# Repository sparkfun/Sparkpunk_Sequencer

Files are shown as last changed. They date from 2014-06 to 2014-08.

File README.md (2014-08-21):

SparkPunk Sequencer
===================

[SparkPunk Sequencer
*SparkPunk Sequencer(KIT-12707)*](https://www.sparkfun.com/products/12707)

The SparkPunk Sequencer is a musical control voltage sequencer designed to control the 
[SparkPunk Sound Generator](https://www.sparkfun.com/products/11177). 
With the pair, you can create ten-step musical motifs, but there are hidden opportunities in the sequencer: 
it can be modified and connected to external hardware in clever and interesting ways. 

Board comes as a soldering kit. 

Repository Contents
-------------------
* **/Hardware** - All Eagle design files (.brd, .sch, .STL)
* **/Sims** - LTSpice files

License Information
-------------------
The hardware is released under [Creative Commons ShareAlike 4.0 International](https://creativecommons.org/licenses/by-sa/4.0/).

Distributed as-is; no warranty is given.

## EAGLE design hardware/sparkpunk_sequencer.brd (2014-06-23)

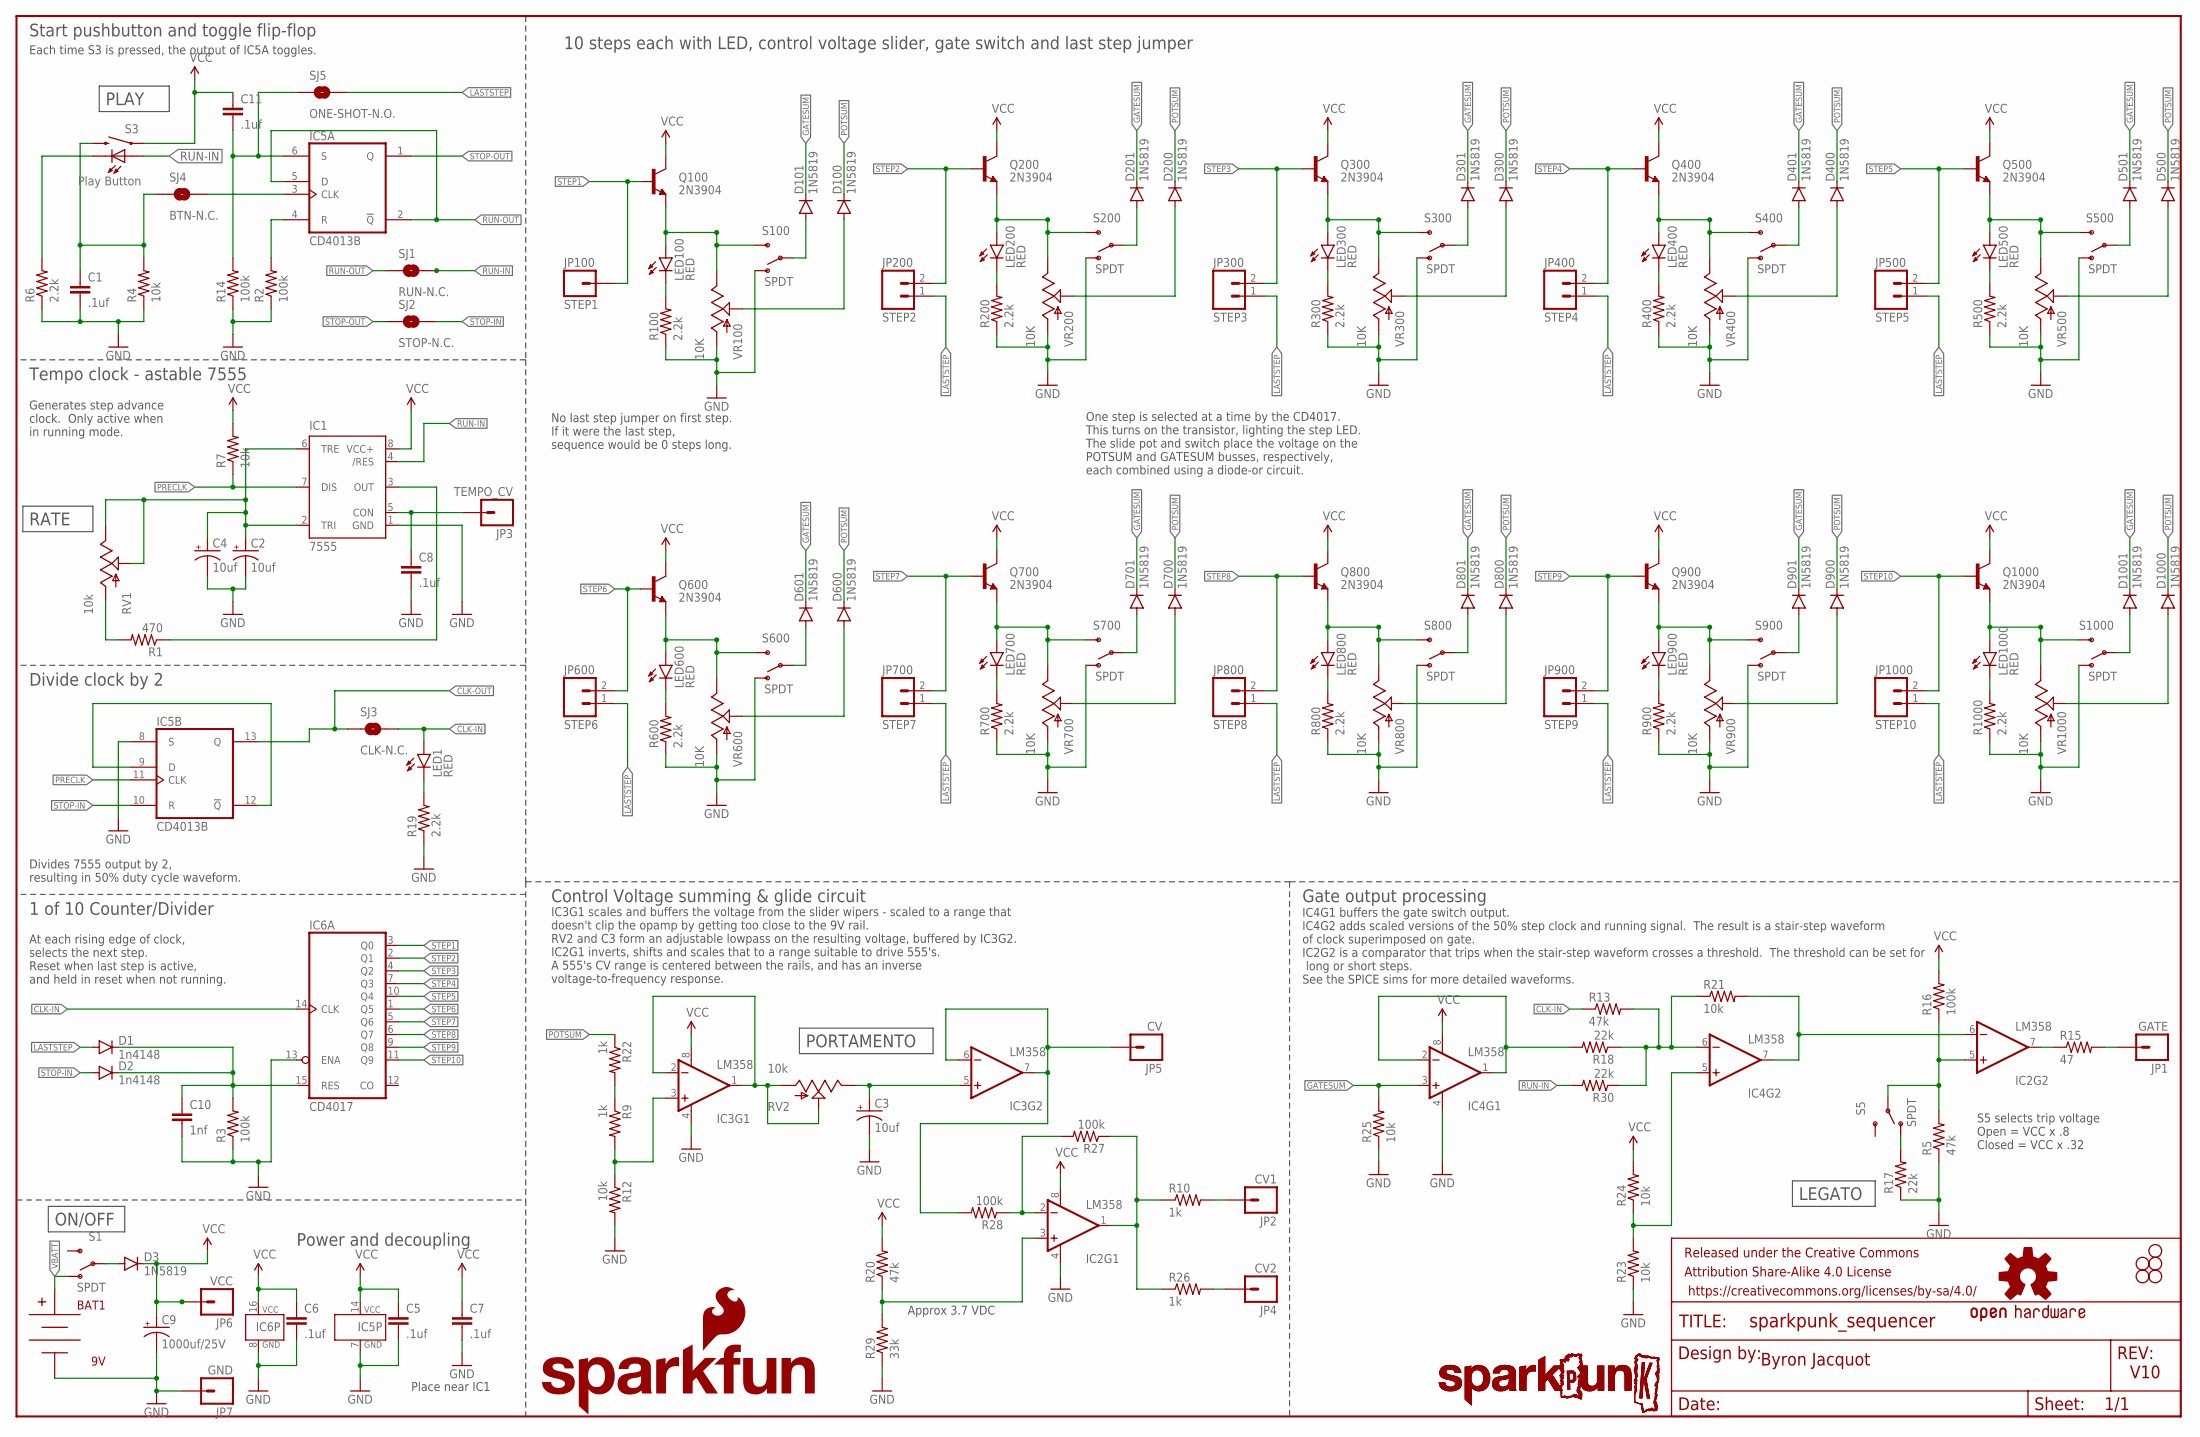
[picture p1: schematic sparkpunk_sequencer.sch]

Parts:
BAT1: 9V; BC9VPC_KIT
C1, C5, C6, C7, C8, C11: .1uf; CAP-PTH-SMALL-KIT
C2, C3, C4: 10uf; CPOL-RADIAL-10UF-25V-KIT
C9: 1000uf/25V; CPOL-RADIAL-1000UF-25V-KIT
C10: 1nf; CAP-PTH-SMALL-KIT
D1, D2: 1n4148; DIODE-1N4148-KIT
D3, D100, D101, D200, D201, D300, D301, D400, D401, D500, D501, D600, D601, D700, D701, D800, D801, D900, D901, D1000, D1001: 1N5819; DIODE-1N4001-KIT
FRAME1: FRAME-LEDGER; CREATIVE_COMMONS
IC1: 7555; DIP08-KIT
IC2, IC3, IC4: LM358; DIP08-KIT
IC5: CD4013B; DIL14-KIT
IC6: CD4017; DIL16-KIT
JP1: GATE; 1X01NS
JP2: CV1; 1X01NS
JP3: TEMPO_CV; 1X01NS
JP4: CV2; 1X01NS
JP5: CV; 1X01NS
JP6: VCC; 1X01NS
JP7: GND; 1X01NS
JP100: STEP1; 1X01NS
JP200: STEP2; 1X02_NO_SILK
JP300: STEP3; 1X02_NO_SILK
JP400: STEP4; 1X02_NO_SILK
JP500: STEP5; 1X02_NO_SILK
JP600: STEP6; 1X02_NO_SILK
JP700: STEP7; 1X02_NO_SILK
JP800: STEP8; 1X02_NO_SILK
JP900: STEP9; 1X02_NO_SILK
JP1000: STEP10; 1X02_NO_SILK
LED1, LED100, LED200, LED300, LED400, LED500, LED600, LED700, LED800, LED900, LED1000: RED; LED5MM-KIT
LOGO1: SPARKPUNK_LOGO.2_INCH_TALL; SPARKPUNK_LOGO_.2
LOGO2: OSHW-LOGOM; OSHW-LOGO-M
LOGO3: SPARKPUNK_LOGO.1INCH_TALL; SPARKPUNK_LOGO_.1
LOGO4: SFE_LOGO_NAME_FLAME.4_INCH; SFE_LOGO_NAME_FLAME_.4
Q100, Q200, Q300, Q400, Q500, Q600, Q700, Q800, Q900, Q1000: 2N3904; TO-92-AMMO
R1: 470; AXIAL-0.3EZ
R2, R3, R14, R16, R27, R28: 100k; AXIAL-0.3EZ
R4, R7, R12, R21, R23, R24, R25: 10k; AXIAL-0.3EZ
R5, R13, R20: 47k; AXIAL-0.3EZ
R6, R19, R100, R200, R300, R400, R500, R600, R700, R800, R900, R1000: 2.2k; AXIAL-0.3EZ
R9, R10, R22, R26: 1k; AXIAL-0.3EZ
R15: 47; AXIAL-0.3EZ
R17, R18, R30: 22k; AXIAL-0.3EZ
R29: 33k; AXIAL-0.3EZ
RV1, RV2: 10k; ALPS_POT_KIT
S1, S5, S100, S200, S300, S400, S500, S600, S700, S800, S900, S1000: SPDT; SWITCH-SPDT_KIT
S3: Play Button; TACTILE-PTH-LED-12MM-EZ
SJ1: RUN-N.C.; SJ_2S-TRACE-PTH
SJ2: STOP-N.C.; SJ_2S-TRACE-PTH
SJ3: CLK-N.C.; SJ_2S-TRACE-PTH
SJ4: BTN-N.C.; SJ_2S-TRACE-PTH
SJ5: ONE-SHOT-N.O.; SJ_2S-PTH
STANDOFF1, STANDOFF2, STANDOFF3, STANDOFF5, STANDOFF6: STAND-OFF
VR100, VR200, VR300, VR400, VR500, VR600, VR700, VR800, VR900, VR1000: 10K; SLIDER-MEDIUM-KIT

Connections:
555OUT: IC1.3 (OUT), R1.P$1 (1)
BTN-OUT: C1.1, R4.P$2 (2), S3.2, SJ4.1
CLK-IN: IC6.14 (CLK), LED1.A, R13.P$1 (1), SJ3.2
CLK-OUT: IC5.13 (Q), SJ3.1
GATESUM: D101.C, D201.C, D301.C, D401.C, D501.C, D601.C, D701.C, D801.C, D901.C, D1001.C, IC4.3 (+IN), R25.P$2 (2)
GND: BAT1.V-, C1.2, C2.2 (-), C3.2 (-), C4.2 (-), C5.2, C6.2, C7.2, C8.2, C9.-, C10.2, IC1.1 (GND), IC2.4 (V-), IC3.4 (V-), IC4.4 (V-), IC5.7 (GND), IC5.8 (S), IC6.8 (GND), IC6.13 (ENA), JP7.1, R2.P$1 (1), R3.P$1 (1), R4.P$1 (1), R5.P$1 (1), R6.P$1 (1), R12.P$2 (2), R14.P$1 (1), R17.P$1 (1), R19.P$1 (1), R23.P$1 (1), R25.P$1 (1), R29.P$1 (1), R100.P$1 (1), R200.P$1 (1), R300.P$1 (1), R400.P$1 (1), R500.P$1 (1), R600.P$1 (1), R700.P$1 (1), R800.P$1 (1), R900.P$1 (1), R1000.P$1 (1), S100.1 (O), S200.1 (O), S300.1 (O), S400.1 (O), S500.1 (O), S600.1 (O), S700.1 (O), S800.1 (O), S900.1 (O), S1000.1 (O), VR100.BOTTOM (A), VR200.BOTTOM (A), VR300.BOTTOM (A), VR400.BOTTOM (A), VR500.BOTTOM (A), VR600.BOTTOM (A), VR700.BOTTOM (A), VR800.BOTTOM (A), VR900.BOTTOM (A), VR1000.BOTTOM (A)
LASTSTEP: D1.A, JP200.1, JP300.1, JP400.1, JP500.1, JP600.1, JP700.1, JP800.1, JP900.1, JP1000.1, SJ5.2
unnamed: LED100.A, Q100.1 (E), S100.3 (S), VR100.TOP (E)
unnamed: LED100.K (C), R100.P$2 (2)
unnamed: D101.A, S100.2
unnamed: D100.A, VR100.WIPER (S)
unnamed: R1.P$2 (2), RV1.P$3 (A)
unnamed: IC3.1 (OUT), IC3.2 (-IN), RV2.P$2 (S), RV2.P$3 (A)
unnamed: C8.1, IC1.5 (CON), JP3.1
unnamed: R6.P$2 (2), S3.C
unnamed: IC5.4 (R), R2.P$2 (2)
unnamed: C2.1 (+), C4.1 (+), IC1.2 (TRI), IC1.6 (TRE), RV1.P$1 (E), RV1.P$2 (S)
unnamed: IC4.1 (OUT), IC4.2 (-IN), R18.P$2 (2)
unnamed: LED1.K (C), R19.P$2 (2)
unnamed: C10.1, D1.C, D2.C, IC6.15 (RES), R3.P$2 (2)
unnamed: IC3.3 (+IN), R9.P$2 (2), R12.P$1 (1)
unnamed: R9.P$1 (1), R22.P$2 (2)
unnamed: IC2.2 (-IN), R27.P$2 (2), R28.P$1 (1)
unnamed: C3.1 (+), IC3.5 (+IN), RV2.P$1 (E)
unnamed: IC2.3 (+IN), R20.P$1 (1), R29.P$2 (2)
unnamed: JP1.1, R15.P$2 (2)
unnamed: IC5.3 (CLK), SJ4.2
unnamed: IC2.5 (+IN), R5.P$2 (2), R16.P$1 (1), S5.2
unnamed: IC2.7 (OUT), R15.P$1 (1)
unnamed: R17.P$2 (2), S5.1 (O)
unnamed: IC5.9 (D), IC5.12 (!Q)
unnamed: LED200.A, Q200.1 (E), S200.3 (S), VR200.TOP (E)
unnamed: LED200.K (C), R200.P$2 (2)
unnamed: D200.A, VR200.WIPER (S)
unnamed: D201.A, S200.2
unnamed: LED300.A, Q300.1 (E), S300.3 (S), VR300.TOP (E)
unnamed: LED300.K (C), R300.P$2 (2)
unnamed: D300.A, VR300.WIPER (S)
unnamed: D301.A, S300.2
unnamed: LED400.A, Q400.1 (E), S400.3 (S), VR400.TOP (E)
unnamed: LED400.K (C), R400.P$2 (2)
unnamed: D400.A, VR400.WIPER (S)
unnamed: D401.A, S400.2
unnamed: LED500.A, Q500.1 (E), S500.3 (S), VR500.TOP (E)
unnamed: LED500.K (C), R500.P$2 (2)
unnamed: D500.A, VR500.WIPER (S)
unnamed: D501.A, S500.2
unnamed: LED600.A, Q600.1 (E), S600.3 (S), VR600.TOP (E)
unnamed: LED600.K (C), R600.P$2 (2)
unnamed: D600.A, VR600.WIPER (S)
unnamed: D601.A, S600.2
unnamed: LED700.A, Q700.1 (E), S700.3 (S), VR700.TOP (E)
unnamed: LED700.K (C), R700.P$2 (2)
unnamed: D700.A, VR700.WIPER (S)
unnamed: D701.A, S700.2
unnamed: LED800.A, Q800.1 (E), S800.3 (S), VR800.TOP (E)
unnamed: LED800.K (C), R800.P$2 (2)
unnamed: D800.A, VR800.WIPER (S)
unnamed: D801.A, S800.2
unnamed: LED900.A, Q900.1 (E), S900.3 (S), VR900.TOP (E)
unnamed: LED900.K (C), R900.P$2 (2)
unnamed: D900.A, VR900.WIPER (S)
unnamed: D901.A, S900.2
unnamed: LED1000.A, Q1000.1 (E), S1000.3 (S), VR1000.TOP (E)
unnamed: LED1000.K (C), R1000.P$2 (2)
unnamed: D1000.A, VR1000.WIPER (S)
unnamed: D1001.A, S1000.2
unnamed: C11.2, IC5.6 (S), R14.P$2 (2), SJ5.1
unnamed: IC4.6 (-IN), R13.P$2 (2), R18.P$1 (1), R21.P$1 (1), R30.P$1 (1)
unnamed: IC3.6 (-IN), IC3.7 (OUT), JP5.1, R28.P$2 (2)
unnamed: IC2.1 (OUT), R10.P$1 (1), R26.P$1 (1), R27.P$1 (1)
unnamed: JP4.1, R26.P$2 (2)
unnamed: JP2.1, R10.P$2 (2)
unnamed: IC2.6 (-IN), IC4.7 (OUT), R21.P$2 (2)
unnamed: IC4.5 (+IN), R23.P$2 (2), R24.P$1 (1)
unnamed: D3.A, S1.2
POTSUM: D100.C, D200.C, D300.C, D400.C, D500.C, D600.C, D700.C, D800.C, D900.C, D1000.C, R22.P$1 (1)
PRECLK: IC1.7 (DIS), IC5.11 (CLK), R7.P$1 (1)
RUN-IN: IC1.4 (/RES), R30.P$2 (2), S3.A, SJ1.2
RUN-OUT: IC5.2 (!Q), IC5.5 (D), SJ1.1
STEP1: IC6.3 (Q0), JP100.1, Q100.2 (B)
STEP2: IC6.2 (Q1), JP200.2, Q200.2 (B)
STEP3: IC6.4 (Q2), JP300.2, Q300.2 (B)
STEP4: IC6.7 (Q3), JP400.2, Q400.2 (B)
STEP5: IC6.10 (Q4), JP500.2, Q500.2 (B)
STEP6: IC6.1 (Q5), JP600.2, Q600.2 (B)
STEP7: IC6.5 (Q6), JP700.2, Q700.2 (B)
STEP8: IC6.6 (Q7), JP800.2, Q800.2 (B)
STEP9: IC6.9 (Q8), JP900.2, Q900.2 (B)
STEP10: IC6.11 (Q9), JP1000.2, Q1000.2 (B)
STOP-IN: D2.A, IC5.10 (R), SJ2.2
STOP-OUT: IC5.1 (Q), SJ2.1
VBATT: BAT1.V+, S1.1 (O)
VCC: C5.1, C6.1, C7.1, C9.+, C11.1, D3.C, IC1.8 (VCC+), IC2.8 (V+), IC3.8 (V+), IC4.8 (V+), IC5.14 (VCC), IC6.16 (VCC), JP6.1, Q100.3 (C), Q200.3 (C), Q300.3 (C), Q400.3 (C), Q500.3 (C), Q600.3 (C), Q700.3 (C), Q800.3 (C), Q900.3 (C), Q1000.3 (C), R7.P$2 (2), R16.P$2 (2), R20.P$2 (2), R24.P$2 (2), S3.4 (1)

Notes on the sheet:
Byron Jacquot
V10
LEGATO
PORTAMENTO
RATE
PLAY
Place near IC1
Power and decoupling
1 of 10 Counter/Divider
Divide clock by 2
Tempo clock - astable 7555
Start pushbutton and toggle flip-flop
Control Voltage summing & glide circuit
Gate output processing
10 steps each with LED, control voltage slider, gate switch and last step jumper
No last step jumper on first step. If it were the last step, sequence would be 0 steps long.
Each time S3 is pressed, the output of IC5A toggles.
Divides 7555 output by 2, resulting in 50% duty cycle waveform.
At each rising edge of clock, selects the next step. Reset when last step is active, and held in reset when not running.
Generates step advance clock. Only active when in running mode.
IC3G1 scales and buffers the voltage from the slider wipers - scaled to a range that doesn't clip the opamp by getting too close to the 9V rail. RV2 and C3 form an adjustable lowpass on the resulting voltage, buffered by IC3G2. IC2G1 inverts, shifts and scales that to a range suitable to drive 555'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
IC4G1 buffers the gate switch output. IC4G2 adds scaled versions of the 50% step clock and running signal. The result is a stair-step waveform of clock superimposed on gate. IC2G2 is a comparator that trips when the stair-step waveform crosses a threshold. The threshold can be set for long or short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
S5 selects trip voltage Open = VCC x .8 Closed = VCC x .32
One step is selected at a time by the CD4017. This turns on the transistor, lighting the step LED. The slide pot and switch place the voltage on the POTSUM and GATESUM busses, respectively, each combined using a diode-or circuit.
Approx 3.7 VDC
ON/OFF

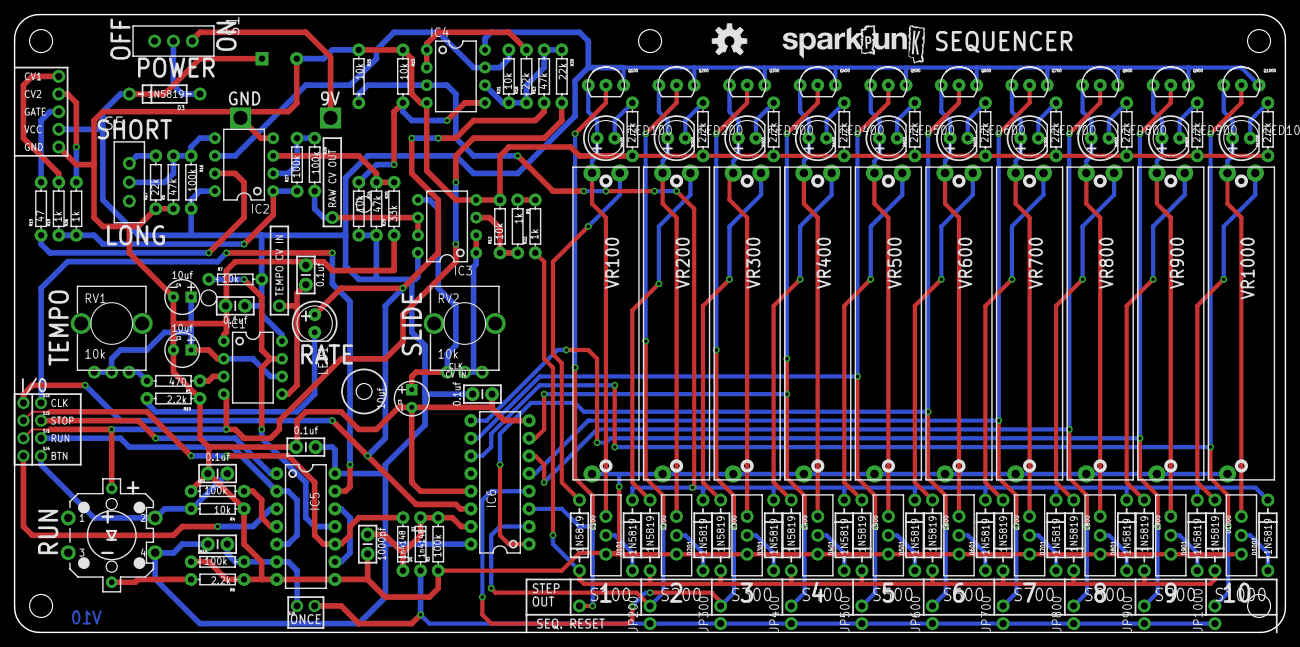
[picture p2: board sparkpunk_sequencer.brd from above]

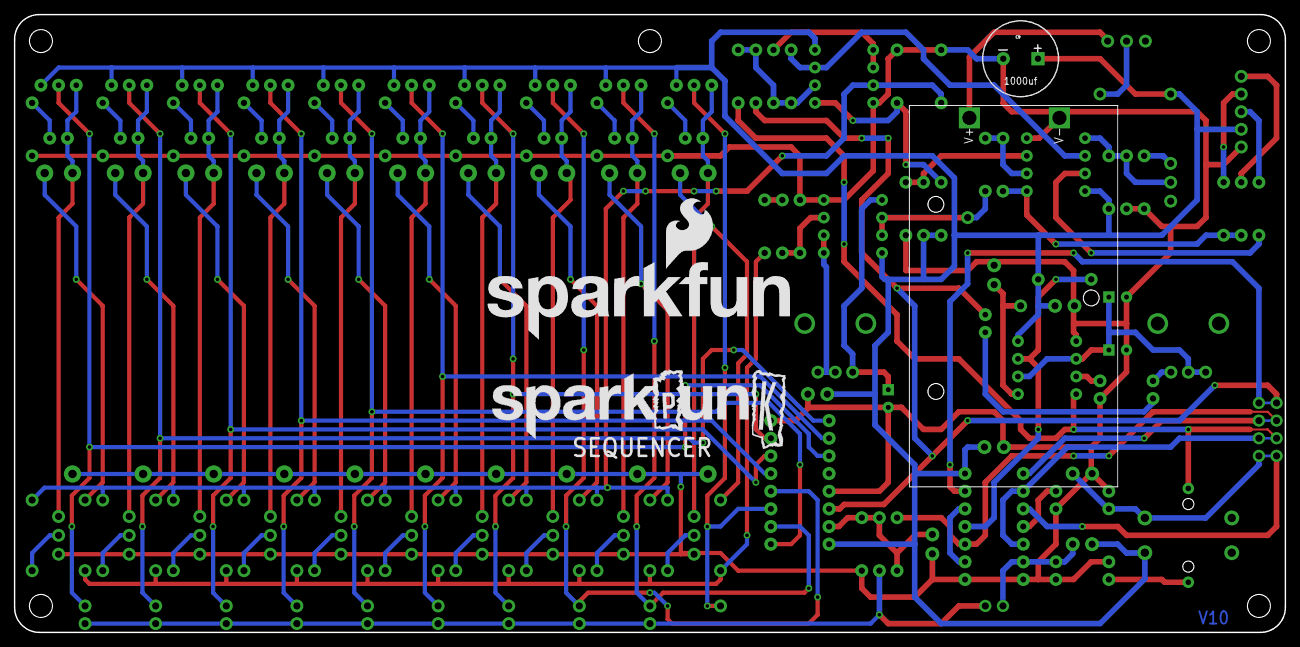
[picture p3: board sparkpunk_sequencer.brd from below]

Board: 2 copper layers, 182.9 x 88.9 mm, 157 parts (4 on the bottom side), 94 nets.

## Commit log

2014-01-03 Initial checkin
    [sparkpunk_sequencer.brd, sparkpunk_sequencer.sch]
2014-01-07 PCB updates after review
    [sparkpunk_sequencer.brd, sparkpunk_sequencer.sch]
2014-01-08 Small updates after creating BOM
    [sparkpunk_sequencer.brd, sparkpunk_sequencer.sch]
2014-04-25 Ready for second proto
    Lots of tweaking on the output stages and other details, based on
    prototype evaluation.
    [sparkpunk_sequencer.brd, sparkpunk_sequencer.sch, sparkpunk_sequencer_bom.csv]
2014-04-25 Ready for second prototype
    Many changes based on prototype evaluation.
    [sparkpunk_sequencer.brd, sparkpunk_sequencer.sch]
2014-04-25 Removing BOM
    [sparkpunk_sequencer_bom.csv]
2014-04-26 After library updates
    Picking up PROD_ID's for a few parts that didn't have them before.
    No changes to the layout.
    [sparkpunk_sequencer.brd, sparkpunk_sequencer.sch]
2014-06-23 Ready for red review
    Incorporating all changes from second round of protos, builder feedback,
    etc.
    [gate-circuit.ods, sparkpunk_sequencer.brd, sparkpunk_sequencer.sch]
2014-08-19 Updating for release
    Mainly bringing SPICE files to match final implementation, small
    notation change on Eagle schematic
    [sparkpunk_sequencer.sch]

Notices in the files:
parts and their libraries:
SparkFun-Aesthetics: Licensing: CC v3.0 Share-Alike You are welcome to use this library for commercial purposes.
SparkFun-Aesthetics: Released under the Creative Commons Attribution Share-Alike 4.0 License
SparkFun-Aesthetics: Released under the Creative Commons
